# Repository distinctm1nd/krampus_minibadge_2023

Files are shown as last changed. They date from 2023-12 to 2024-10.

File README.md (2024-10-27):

# Krampus Minibadge Instructions

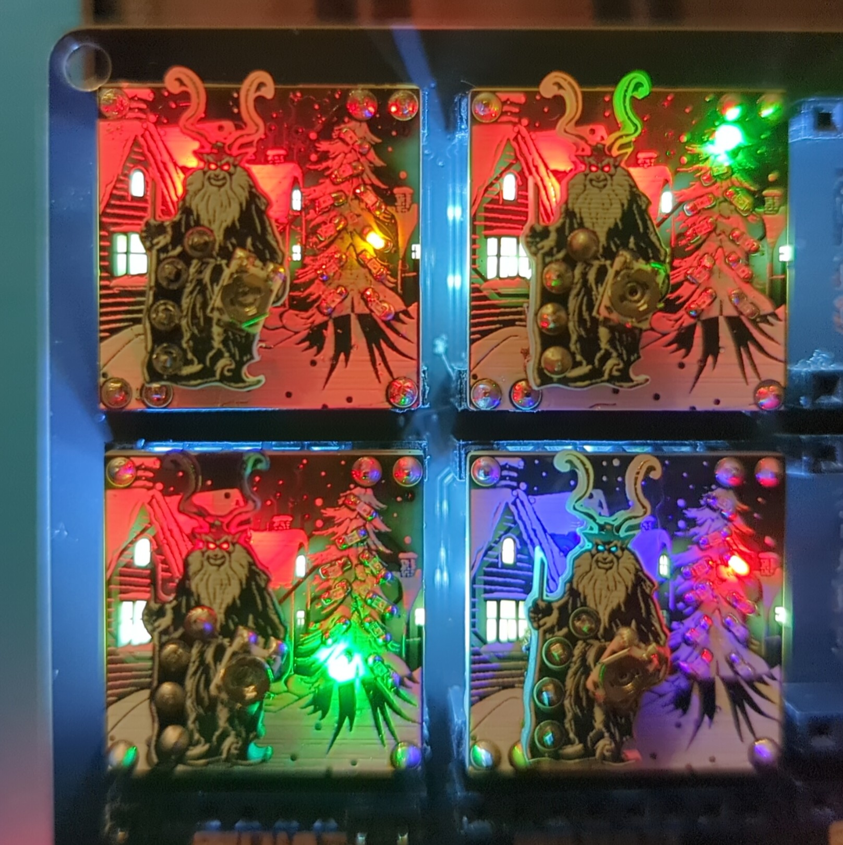
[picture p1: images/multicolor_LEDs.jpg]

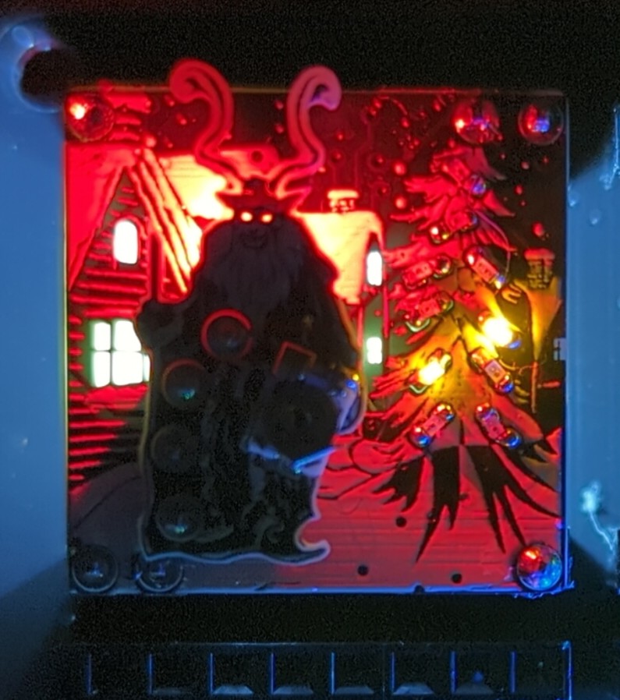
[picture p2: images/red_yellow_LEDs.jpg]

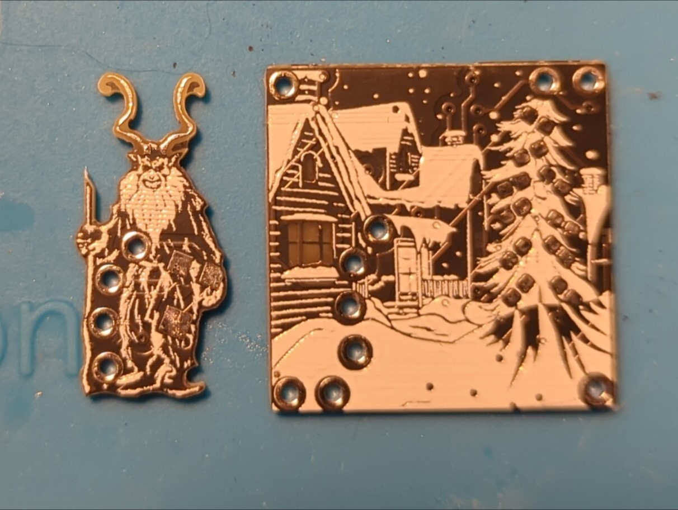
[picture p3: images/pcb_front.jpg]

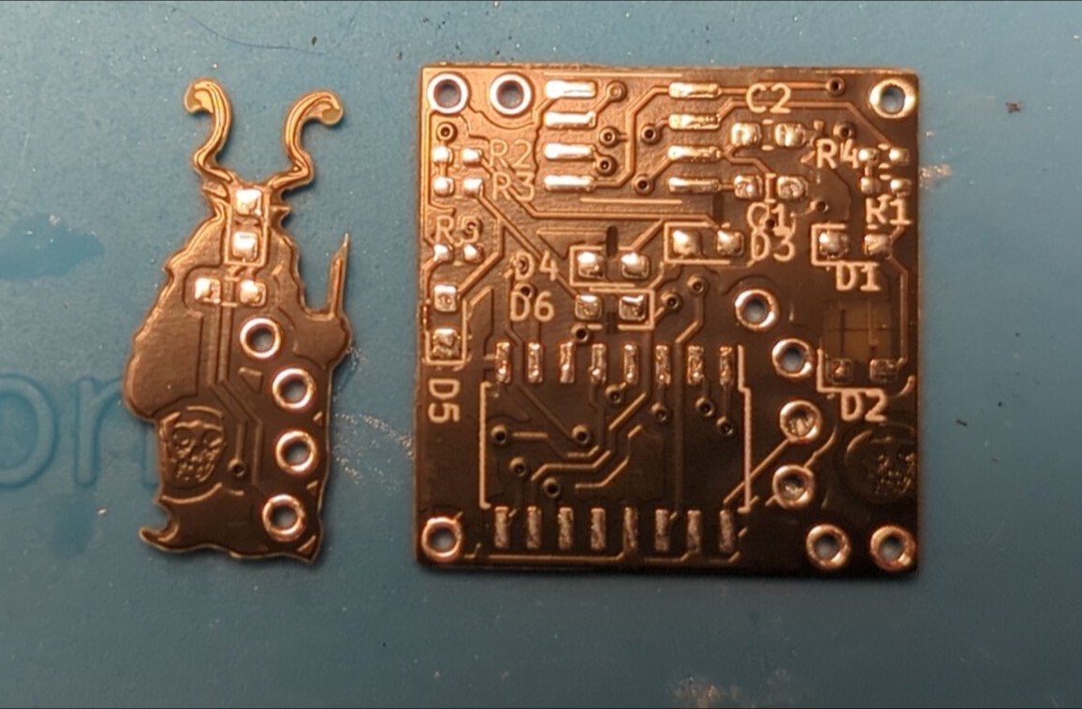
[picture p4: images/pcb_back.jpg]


## Components

- Main minibadge pcb
- Krampus add-on pcb
- 0.1uF Capacitor (0603) - marked orange
- 22uF Capacitor (0603) - marked blue
- 6- smd white LEDs (0603) - these are unmarked
- A mix of at least 10 (should have extras) red, yellow, green LEDs (0402) - these are marked with their associated color
- 3- 5.1 ohm resistors (0402) - these are marked green and you should have an extra
- 5.1k ohm resistor (0402) - marked red
- UV LED (0805) - unmarked
- 15 ohm resistor (0603)
- 68 ohm resistor (0402) - marked black
- TLC555 timer
- CD4017 decade counter
- 5- 2-pin male 2.54 headers
- 10k ohm potentiometer

## Assembly Instructions

Double check components against size, indicated color, and printed info on component (where available). I included extra of the 0402 components so don't use count to determine where they go. 

Start on back of main board:

- Solder the two ICs (TLC555 and CD4017) according to the orientation below. Note that there is a white line that marks the location of pin 1 for each of them.  

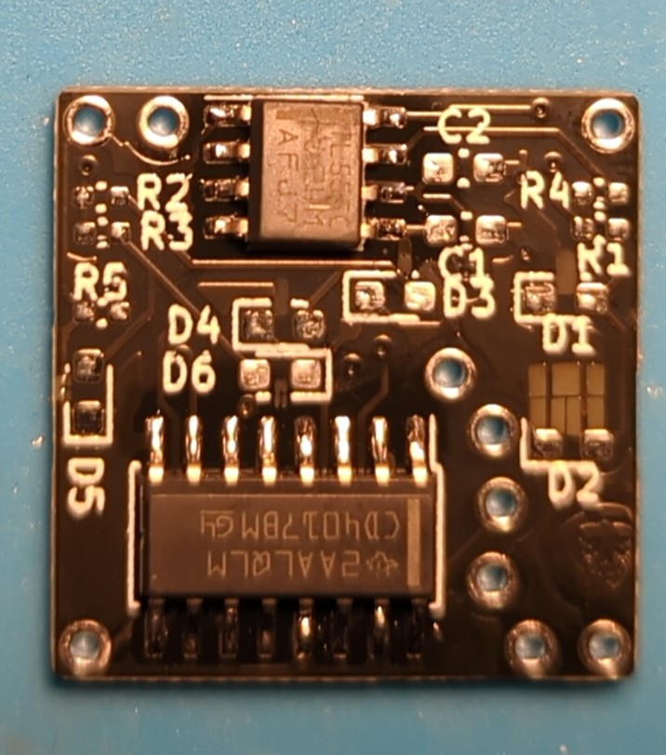
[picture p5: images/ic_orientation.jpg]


- Solder the (0603) 0.1 uF capacitor to C1 (marked orange, orientation doesn't matter)
- Solder the (0603) 22 uF capacitor to C2 (marked blue, orientation doesn't matter)
- Solder the (0402) 5.1k ohm resistor to R4 (marked red)
- Solder (0402) 5.1 ohm resistors to R1, R2 and R3 (marked green)
- Solder (0402) 68 ohm resistor to R5 (marked black)
- Solder (0603) white LEDs to D1, D2, D3, D4, D5, D6. These are the only LEDs that don't have a marked color. I recommend side mounting all of these LEDs (except D5) so the light is facing up. I recommend reverse mounting D5 so that the light is shining toward the board.

Move to the front: 

- The tree has red, green and yellow LEDs (0402, marked with associated color) that can be placed where you would like. I recommend starting with one color and place 3-4 of them about equal distance from each other around the tree. Then do the next color and the last. The cathodes of the LEDs are not clearly marked. They are oriented in the same direction so that the cathode is on the bottom side (closest to the bottom of the board). See image below - the red dot at the lower side of each LED is the cathode.

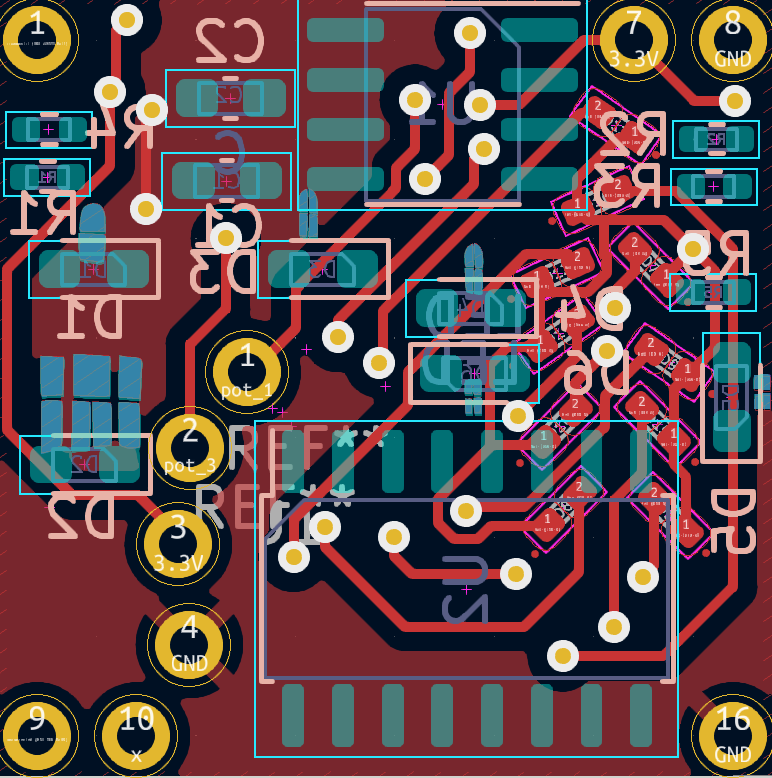
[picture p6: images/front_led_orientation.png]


Move to the Krampus cutout and start on the back:

- Solder the (0603) 15 ohm resistor to R1. Double check the resistor number and don't mix it up with the 5.1k ohm (0603) resistor that is also included.
- Solder the (0805) UV LED (marked purple) to D1. Reverse mount so that the light is shining toward the board. Note: the pads are for an 0603 size component but I messed up and ordered 0805 so you'll have to make it fit!
- Second note: If you'd like a different color LED for the Krampus, change R1 accordingly. For instance, if you want a red LED, you'll need a 68 ohm resistor for R1. 

Move to the front:

- Solder the potentiometer.

I recommend checking that everything is working correctly before soldering any of the header pins because adjusting some of the components is difficult once they are soldered. 

Attach the Krampus cut-out to the main board with 4 header pins (don't solder immediately). Power the badge with the two pins on the top right corner. If everything is working correctly, the 6 white LEDs on the back of the board and the Krampus LED will light up and stay on. The lights on the tree will begin to blink and you'll be able to adjust the blink rate with the potentiometer. If all of this is working correctly, then solder the remaining headers. 

- Feel free to message me with any questions.
